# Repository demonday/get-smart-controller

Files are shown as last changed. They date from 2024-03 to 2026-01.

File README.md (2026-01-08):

# Modern Replacement for "GET" Smart Wireless Lighting System Controller

## Project Intro
I have a aging Wireless Lighting System from a UK company called GET, from circa 2007. Its now so old in fact, that its no longer manufatured, and the company is no longer in existance.
The setup includes a battery-operated controller (replacing the traditional UK light switch) and some mains supplied receivers to operate the lights. I buried the recievers behind the plasterboard in my apartment's ceiling when I installed the system.
Its operated flawlessly since then, I don't think I've ever changed the batteries in the controller, which is testament to its solid design.

It is however, missing integration with home automation (I use Home Assistant & Alexa). Its now a deal breaker. I could replace them with somethine else, and repair the plaster.... 
... but rather than add to the e-waste pile, I thought I'd put one of those microcontroller's I have in a box to good use.

## Side Quests
Typically for me, I'm also diving into a few related technologies as part of this project:
- **Zephyr**: I'm curious to learn this framework.
- **Home Assistant Integration**: I use HA for all my other stuff so this is given.
- **Thread/Matter**: I have tons Zigbee devices already, and want learn more about the newer connected device protocols.

Built with Zephyr v3.6.0

# Reverse Engineering the Controller
After some snooping inside the contoller it seems to be 433Mhz FSK, based on a HiMark TX4915-LF RF chip. Only datasheets HiMark TX4915 say its for ASK, but the silksreen on the transmiter clearly says 433 FSK.

## My Controller Setup
From the [GET Smart Wireless Lighting System Manual](https://www.tlc-direct.co.uk/Technical/DataSheets/GET/Smart_user.pdf) I'm using the controller in "Dimming Mode", with 2 lights, on buttons 1 and 2 respectively.

## Sniffing the data
Before I opened the controller 
Bring on the Hack RF One. 

# Upgrading the GET - Smart Wireless Lighting System Controller

## Reach Out
For collaboration or feedback, please feel free to contact me at [ngormley at armadillo.ie]

*Thank you for your interest*

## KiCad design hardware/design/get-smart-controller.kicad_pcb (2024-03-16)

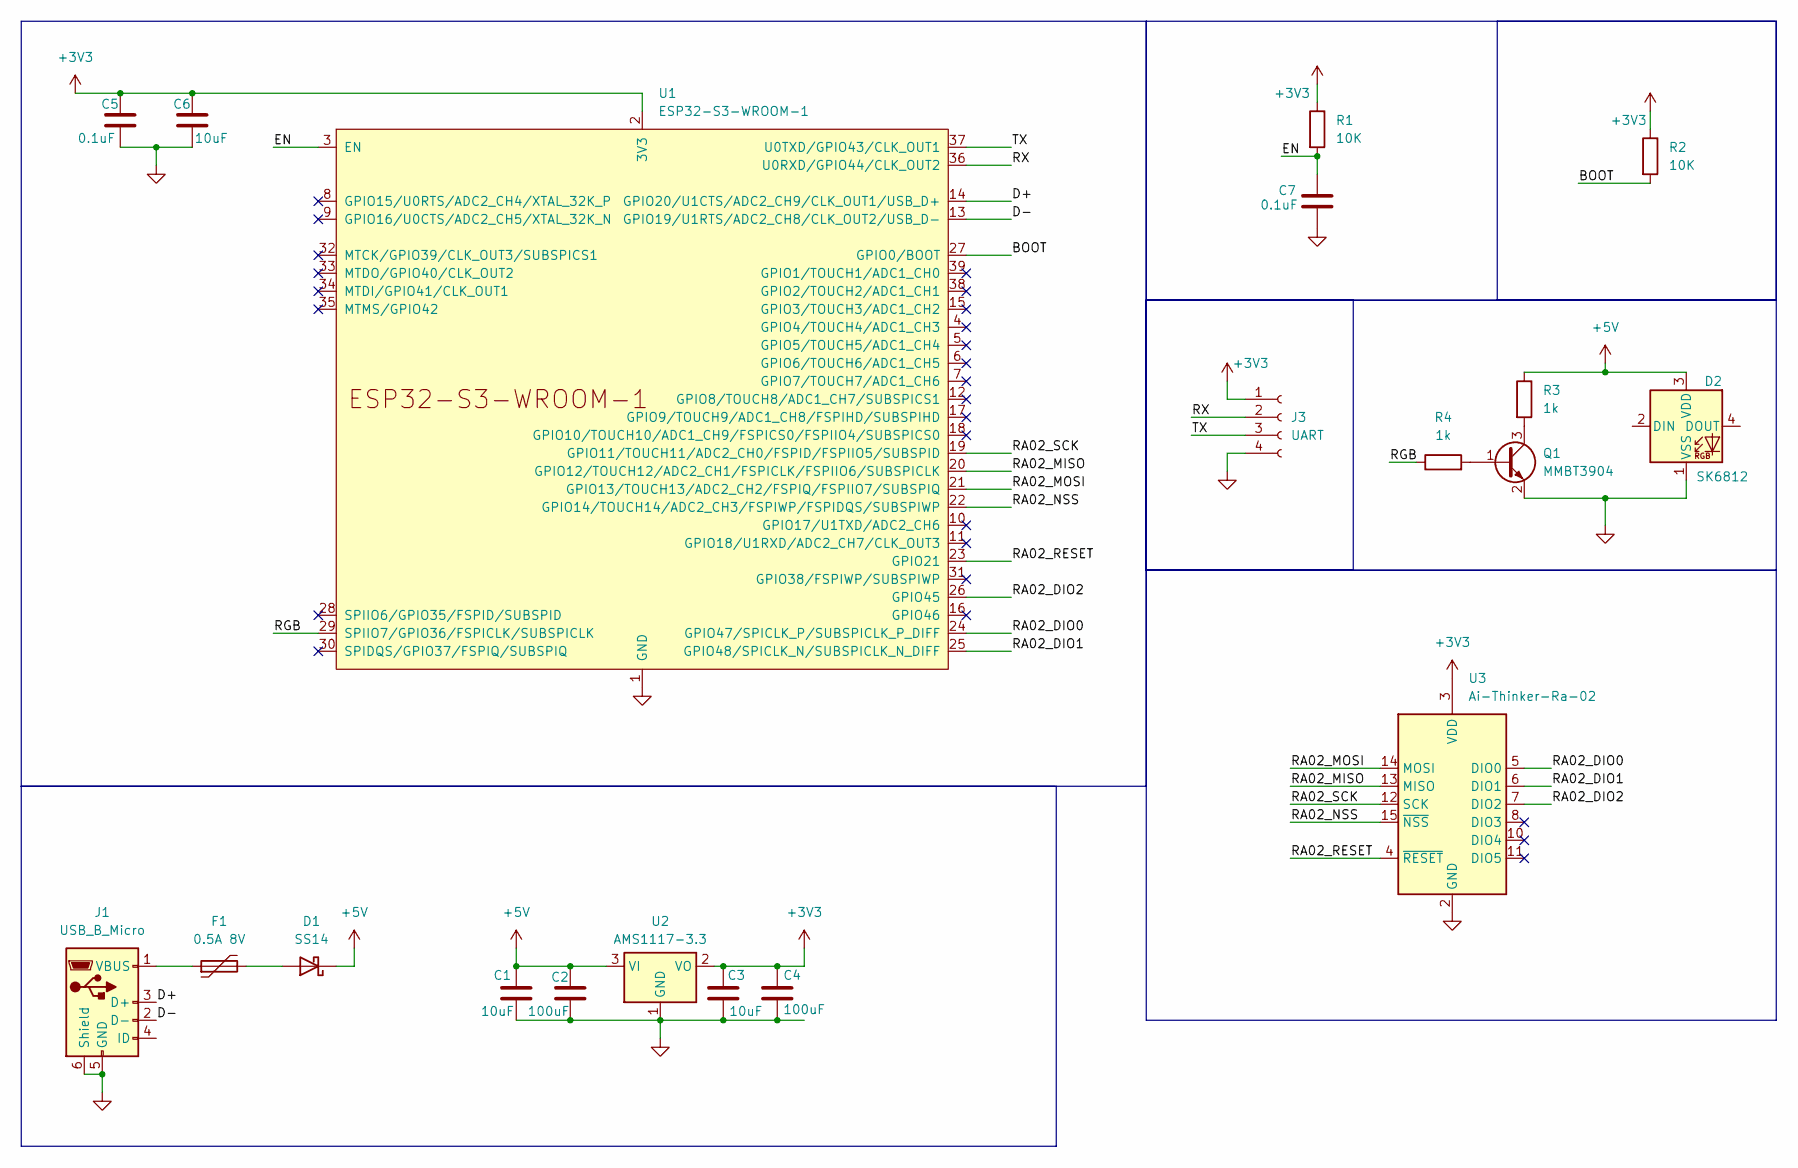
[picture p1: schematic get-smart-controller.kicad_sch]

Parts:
C1, C3, C6: 10uF; C_0805_2012Metric_Pad1.18x1.45mm_HandSolder
C2, C4: 100uF; C_1206_3216Metric_Pad1.33x1.80mm_HandSolder
C5, C7: 0.1uF; C_0805_2012Metric_Pad1.18x1.45mm_HandSolder
D1: SS14; D_SOD-323_HandSoldering
D2: SK6812; LED_SK6812_PLCC4_5.0x5.0mm_P3.2mm
F1: 0.5A 8V; Fuse_1206_3216Metric_Pad1.42x1.75mm_HandSolder
J1: USB_B_Micro; USB_Micro-B_Custom
J3: UART; JST_PH_S4B-PH-K_1x04_P2.00mm_Horizontal
Q1: MMBT3904; SOT-23
R1, R2: 10K; R_0805_2012Metric_Pad1.20x1.40mm_HandSolder
R3, R4: 1k; R_0805_2012Metric_Pad1.20x1.40mm_HandSolder
U1: ESP32-S3-WROOM-1
U2: AMS1117-3.3; SOT-223-3_TabPin2
U3: Ai-Thinker-Ra-02; Ai-Thinker-Ra-01-LoRa

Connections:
+3V3: C3.1, C4.1, C5.1, C6.1, J3.1, R1.1, R2.1, U1.2 (3V3), U2.2 (VO), U3.3 (VDD)
+5V: C1.1, C2.1, D1.1 (K), D2.3 (VDD), R3.1, U2.3 (VI)
/BOOT: R2.2, U1.27 (GPIO0/BOOT)
/D+: J1.3 (D+), U1.14 (GPIO20/U1CTS/ADC2_CH9/CLK_OUT1/USB_D+)
/D-: J1.2 (D-), U1.13 (GPIO19/U1RTS/ADC2_CH8/CLK_OUT2/USB_D-)
/EN: C7.1, R1.2, U1.3 (EN)
/RA02_DIO0: U1.24 (GPIO47/SPICLK_P/SUBSPICLK_P_DIFF), U3.5 (DIO0)
/RA02_DIO1: U1.25 (GPIO48/SPICLK_N/SUBSPICLK_N_DIFF), U3.6 (DIO1)
/RA02_DIO2: U1.26 (GPIO45), U3.7 (DIO2)
/RA02_MISO: U1.20 (GPIO12/TOUCH12/ADC2_CH1/FSPICLK/FSPIIO6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), U3.13 (MISO)
/RA02_MOSI: U1.21 (GPIO13/TOUCH13/ADC2_CH2/FSPIQ/FSPIIO7/S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), U3.14 (MOSI)
/RA02_NSS: U1.22 (GPIO14/TOUCH14/ADC2_CH3/FSPIWP/FSPIDQS/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), U3.15 (~NSS)
/RA02_RESET: U1.23 (GPIO21), U3.4 (~RESET)
/RA02_SCK: U1.19 (GPIO11/TOUCH11/ADC2_CH0/FSPID/FSPIIO5/S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), U3.12 (SCK)
/RGB: R4.1, U1.29 (SPIIO7/GPIO36/FSPICLK/SUBSPICLK)
/RX: J3.2, U1.36 (U0RXD/GPIO44/CLK_OUT2)
/TX: J3.3, U1.37 (U0TXD/GPIO43/CLK_OUT1)
GND: C1.2, C2.2, C3.2, C4.2, C5.2, C6.2, C7.2, D2.1 (VSS), J1.5 (GND), J1.6 (Shield), J3.4, Q1.2 (E), U1.1 (GND), U1.40 (GND), U1.41 (GND), U2.1 (GND), U3.1 (GND), U3.2 (GND), U3.9 (GND), U3.16 (GND)
unnamed: D1.2 (A), F1.2
unnamed: F1.1, J1.1 (VBUS)
unnamed: Q1.1 (B), R4.2
unnamed: Q1.3 (C), R3.2

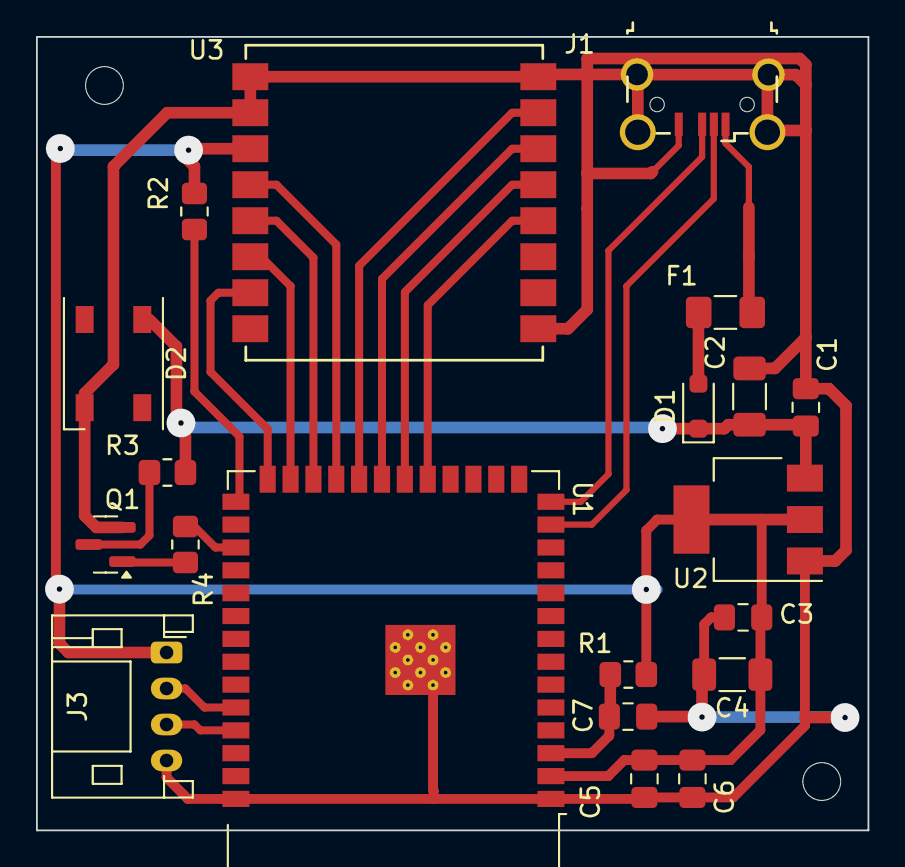
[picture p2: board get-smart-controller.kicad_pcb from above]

Board: 2 copper layers, 46.2 x 44.1 mm, 22 parts (0 on the bottom side), 22 nets.

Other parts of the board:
H1, H3: MountingHole_2.1mm

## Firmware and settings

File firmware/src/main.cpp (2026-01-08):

#include <app_version.h>
#include <stdlib.h>
#include <string.h>
#include <zephyr/device.h>
#include <zephyr/kernel.h>
#include <zephyr/logging/log.h>
#include <zephyr/net/mqtt.h>
#include <zephyr/zbus/zbus.h>
#include <zephyr/drivers/watchdog.h>

#include "config_mgr.h"
#include "controller.h"
#include "mqtt_thread.h"
#include "radio.h"
#include "wifi.h"

controller_t *controller;

ZBUS_CHAN_DEFINE(chan_state_updates,   /* Name */
                 struct state_update,  /* Message type */
                 NULL,                 /* Validator */
                 NULL,                 /* User data */
                 ZBUS_OBSERVERS_EMPTY, /* observers */
                 ZBUS_MSG_INIT(.channel = -1, .state = -1, .brightness = -1));

/* 1000 msec = 1 sec */
#define WDT_FEED_INTERVAL_MS 1000

LOG_MODULE_REGISTER(gs, CONFIG_GETSMART_LOG_LEVEL);

extern "C"
{
  int main(void)
  {
    LOG_INF("GET Smart Wireless Lighting System Controller (%s) \n",
            APP_VERSION_STRING);

    const struct device *wdt;
    int wdt_channel_id;
    struct wdt_timeout_cfg wdt_config = {
        .window = {
            .min = 0,
            .max = 10000, // 10 seconds timeout
        },
        .callback = NULL, // NULL means system reset on timeout
        .flags = WDT_FLAG_RESET_SOC,
    };

    wdt = DEVICE_DT_GET(DT_ALIAS(watchdog0));
    if (!device_is_ready(wdt))
    {
      LOG_ERR("Watchdog device not ready");
      return -1;
    }

    wdt_channel_id = wdt_install_timeout(wdt, &wdt_config);
    if (wdt_channel_id < 0)
    {
      LOG_ERR("Watchdog install error");
      return -1;
    }

    if (wdt_setup(wdt, 0) < 0)
    {
      LOG_ERR("Watchdog setup error");
      return -1;
    }

    wifi_init();

    LOG_INF("Sleeping so wifi can connect");
    k_sleep(K_MSEC(5000));
    wdt_feed(wdt, wdt_channel_id);
    k_sleep(K_MSEC(5000));

    /* Setup the device config */
    /* TODO Move to board? */
    int res = cfg_init();
    if (res < 0)
    {
      LOG_INF("Failed to init configuration.");
      return res;
    }
    cfg_inc_boot();
    cfg_print();

    static char device_id[CFG_SIZE_DEVICEID_ID];
    // static char *device_id = "0f3def"

    cfg_get_value(CFG_DEVICEID_ID, &device_id, CFG_SIZE_DEVICEID_ID);

    controller = (controller_t *)malloc(sizeof(controller_t));
    controller->num_lights = 2; // TODO
    controller->device_id = device_id;
    controller->state_update_channel = (struct zbus_channel *)&chan_state_updates;

    // LOG_INF("radio pointer (main): %p", (void *)&controller->radio);

    mqtt_thread_init(controller);

    radio_init();

    while (1)
    {
      k_sleep(K_SECONDS(1));
      wdt_feed(wdt, wdt_channel_id);
    }

    return 0;
  }
}

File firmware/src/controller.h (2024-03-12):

#ifndef __CONTROLLER__
#define __CONTROLLER__
#include <stdbool.h>
#include <stdint.h>
#include <zephyr/kernel.h>
#include <zephyr/zbus/zbus.h>

/** Controller Channels (i.e. 4 Lights or Scenes) */

#define CHANNEL_0 0
#define CHANNEL_1 1
#define CHANNEL_2 2
#define CHANNEL_3 3
#define CHANNEL_COUNT 4  // I only have 2 lights

/** Controller Operations (as transmitted by the remote switch) */
#define OP_ON 0
#define OP_OFF 1
#define OP_DIM_UP 2
#define OP_DIM_DOWN 3
#define OP_COUNT 4

#define STATE_OFF 0
#define STATE_ON 1

/** Number of button presses to go from full brightness to off */
#define DIM_LEVELS 64

#define ROWS_PER_CHANNEL 6
/**
 * Each row has a Pulse Sequence Length, followed by the sequence
 * of 1s that get transmitted before another 0 gets transmitted.
 *
 * Lists all the Controller Operations for each channel beginning
 * at OP_ON for CHANNEL_0
 */
// clang-format off
#define PULSESEQ {4, 4, 3, 1, 2, 0, 0, \
                  2, 4, 6, 0, 0, 0, 0, \
                  4, 4, 1, 1, 0, 0, 0, \
                  6, 5, 1, 1, 1, 1, 1, \
                  4, 4, 3, 2, 1, 0, 0, \
                  6, 5, 1, 1, 1, 1, 1, \
                  4, 3, 4, 1, 2, 0, 0, \
                  2, 3, 7, 0, 0, 0, 0, \
                  3, 3, 5, 1, 1, 0, 0, \
                  6, 5, 1, 1, 1, 1, 1, \
                  4, 3, 4, 2, 1, 0, 0, \
                  6, 5, 1, 1, 1, 1, 1} 
 // clang-format on    

/** Size of a row above */
#define PLUSESEQ_SIZE 7

/* Number of byes in the actual message transmitted by the radio*/
#define TRANSMIT_BUF_SIZE 11

struct light_state {
  int state;
  int brightness;
};

typedef struct controller {
  struct zbus_channel *state_update_channel;
  char* device_id;
  uint8_t num_lights;
  struct light_state state[CHANNEL_COUNT];
} controller_t;

struct state_update {
  int channel;
  int state;
  int brightness;
};

typedef struct f_sum {
  sys_snode_t snode;
  struct state_update su;
} f_sum_t;

#ifdef __cplusplus
extern "C" {
#endif

int request_state(struct controller *controller, int channel, int state,
                  bool set_brightness, int brightness);

#ifdef __cplusplus
}
#endif

#endif /* __CONTROLLER__ */

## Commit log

2023-12-18 First pass at controller for GET - Smart Wireless Lighting System
2024-01-02 integrate radiolib and refactor for esp32s3
2024-01-03 working prototype supports on/off and dim.
2024-02-05 Added Espressif KiCad resources
2024-02-06 Added KiCad exclusions
2024-02-06 Added Homebrew PCB in KiCad
    [get-smart-controller.kicad_pcb, get-smart-controller.kicad_sch]
2024-02-08 Updated PCB with holes
    [get-smart-controller.kicad_pcb, get-smart-controller.kicad_sch]
2024-03-12 Add additional Ground path
    [get-smart-controller.kicad_pcb]
2024-03-12 fixed issues with getting the byte sequences
    [controller.h, main.cpp]
2024-03-16 Added RGB led, and fixed foorptint for USB Micro
    [get-smart-controller.kicad_pcb, get-smart-controller.kicad_sch]
2026-01-08 Add watchdog timer and improve system stability
    - Implement 10-second watchdog timer with 1-second feed interval
    - Fix WiFi connectivity and MQTT authentication issues
    - Configure USB serial console for ESP32-S3
    - Improve memory management and thread safety
    - Add runtime statistics for heap and thread monitoring
    - Fix device ID storage and configuration management
    - Update WiFi connection flow with proper state handling
    [main.cpp]
